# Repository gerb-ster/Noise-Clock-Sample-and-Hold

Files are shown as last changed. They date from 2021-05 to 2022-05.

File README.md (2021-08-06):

# Noise, Clock and S&H

This module is a sort of 3-in-1 module, containing 4 types of noise, a clock generator based on a 555 IC and a sample-and-hold section. It’s based on / inspired by the Noise & S&H module by Niklas Ronnberg. It has a slew function, which is really nice, use it quit a lot.

The noise colors are White, Blue, Pink & Red. They are created by filtering the white noise. There are 2 trimmer pots on the back, one to set the overal noise volume and one to set the pulse length of the clock output.

## Status: Finished

- done: first schematic & board design
- done: breadboard and test
- done: design frontpanel
- done: order PCB and build prototype

## Pot Values

Since the earlier schematic didn't include the pot values, here they are (schematics have also been updated)

Slew & Attn: 100k lin
Rate: 1M log

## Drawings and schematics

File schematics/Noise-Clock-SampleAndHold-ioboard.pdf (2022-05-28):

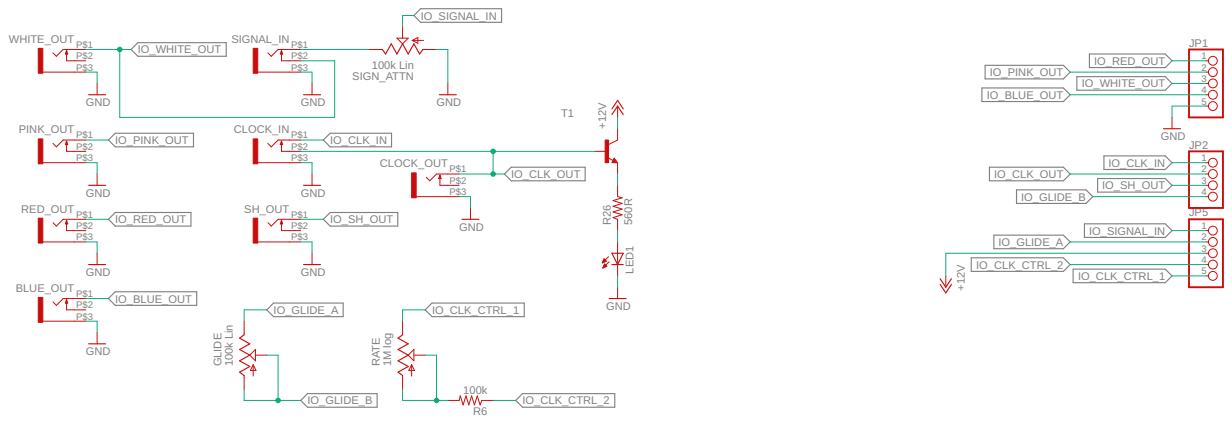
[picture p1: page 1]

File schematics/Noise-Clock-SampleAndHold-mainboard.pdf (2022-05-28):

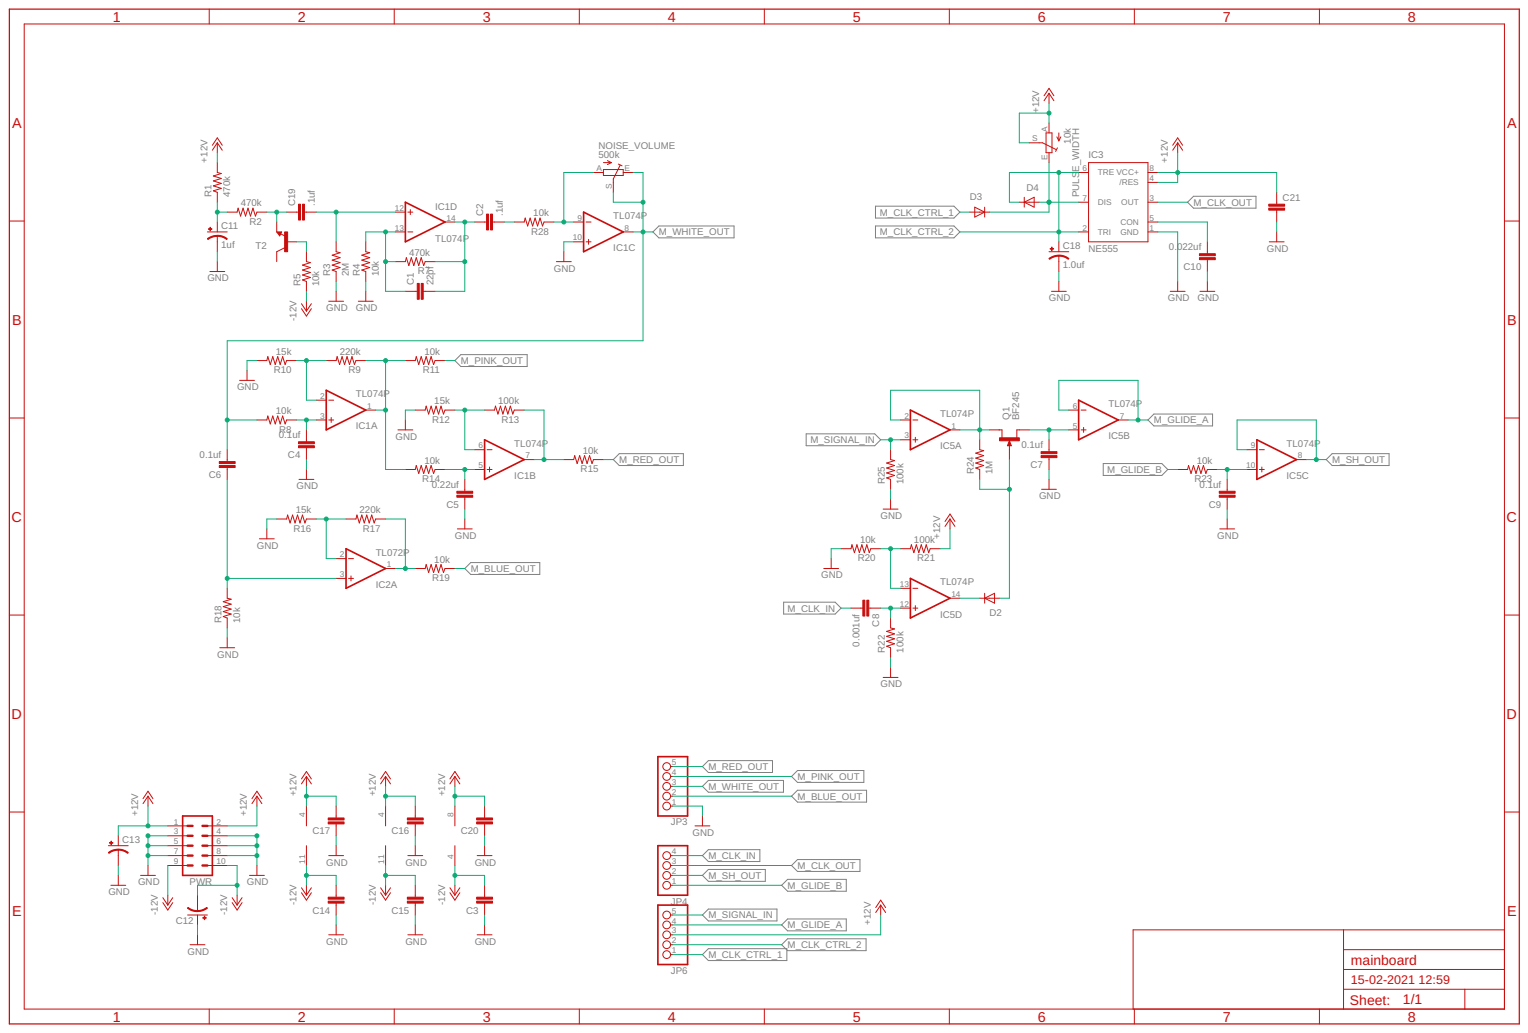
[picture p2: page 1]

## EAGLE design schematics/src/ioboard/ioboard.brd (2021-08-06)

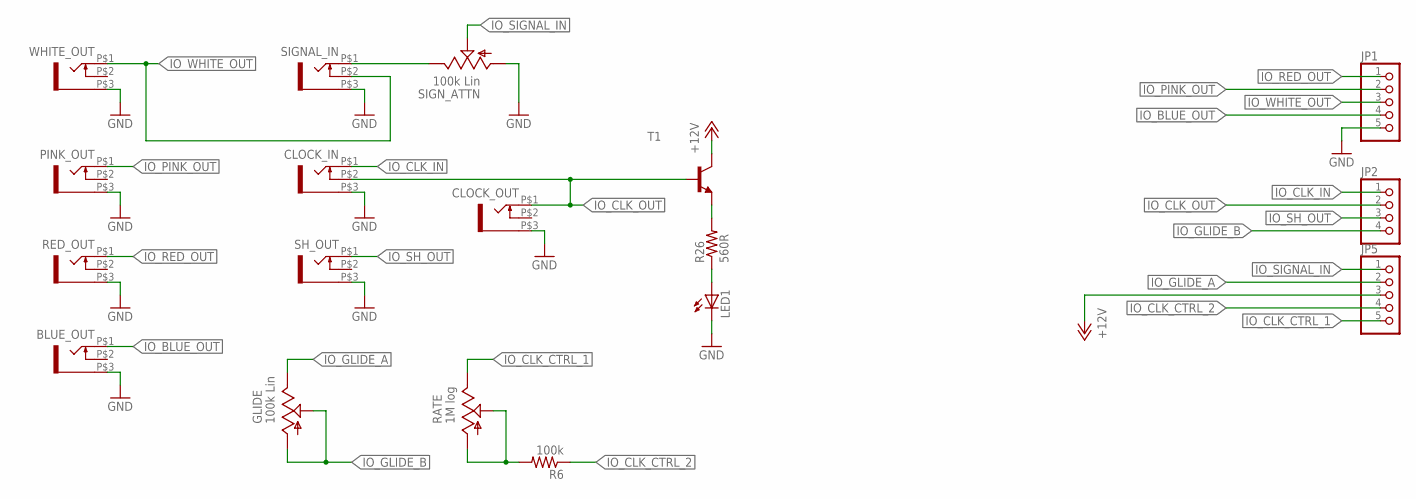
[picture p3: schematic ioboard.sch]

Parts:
BLUE_OUT: WQP-PJ301M-12_JACK
CLOCK_IN: WQP-PJ301M-12_JACK
CLOCK_OUT: WQP-PJ301M-12_JACK
GLIDE: 100k Lin; EVUF
JP1, JP5: PINHD-1X5; 1X05
JP2: PINHD-1X4; 1X04
LED1: LED3MM
PINK_OUT: WQP-PJ301M-12_JACK
R6: 100k; 0204/7
R26: 560R; 0204/7
RATE: 1M log; EVUF
RED_OUT: WQP-PJ301M-12_JACK
SH_OUT: WQP-PJ301M-12_JACK
SIGNAL_IN: WQP-PJ301M-12_JACK
SIGN_ATTN: 100k Lin; EVUF
T1: BC550-NPN-TO92-CBE; TO92-CBE
WHITE_OUT: WQP-PJ301M-12_JACK

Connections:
+12V: JP5.3, T1.C
GND: BLUE_OUT.P$3 (1), CLOCK_IN.P$3 (1), CLOCK_OUT.P$3 (1), JP1.5, LED1.K (C), PINK_OUT.P$3 (1), RED_OUT.P$3 (1), SH_OUT.P$3 (1), SIGNAL_IN.P$3 (1), SIGN_ATTN.1 (A), WHITE_OUT.P$3 (1)
IO_BLUE_OUT: BLUE_OUT.P$1 (2), JP1.4
IO_CLK_CTRL_1: JP5.5, RATE.3 (E)
IO_CLK_CTRL_2: JP5.4, R6.1
IO_CLK_IN: CLOCK_IN.P$1 (2), JP2.1
IO_CLK_OUT: CLOCK_IN.P$2 (3), CLOCK_OUT.P$1 (2), JP2.2, T1.B
IO_GLIDE_A: GLIDE.3 (E), JP5.2
IO_GLIDE_B: GLIDE.1 (A), GLIDE.2 (S), JP2.4
IO_PINK_OUT: JP1.2, PINK_OUT.P$1 (2)
IO_RED_OUT: JP1.1, RED_OUT.P$1 (2)
IO_SH_OUT: JP2.3, SH_OUT.P$1 (2)
IO_SIGNAL_IN: JP5.1, SIGN_ATTN.2 (S)
IO_WHITE_OUT: JP1.3, SIGNAL_IN.P$2 (3), WHITE_OUT.P$1 (2)
unnamed: SIGNAL_IN.P$1 (2), SIGN_ATTN.3 (E)
unnamed: LED1.A, R26.1
unnamed: R26.2, T1.E
unnamed: R6.2, RATE.1 (A), RATE.2 (S)

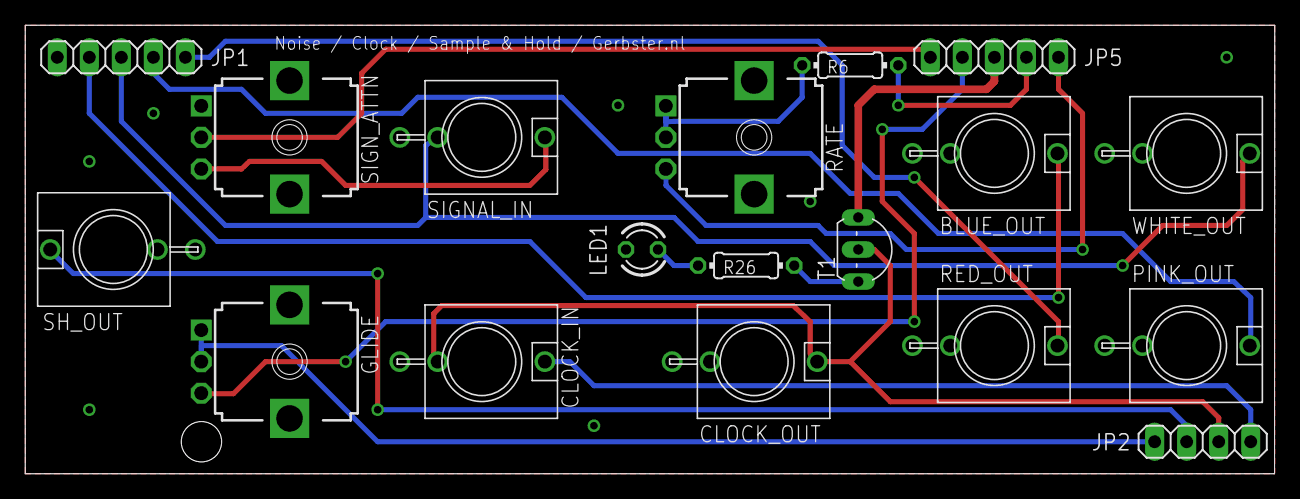
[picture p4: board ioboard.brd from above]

Board: 2 copper layers, 99.1 x 35.6 mm, 18 parts (0 on the bottom side), 18 nets.

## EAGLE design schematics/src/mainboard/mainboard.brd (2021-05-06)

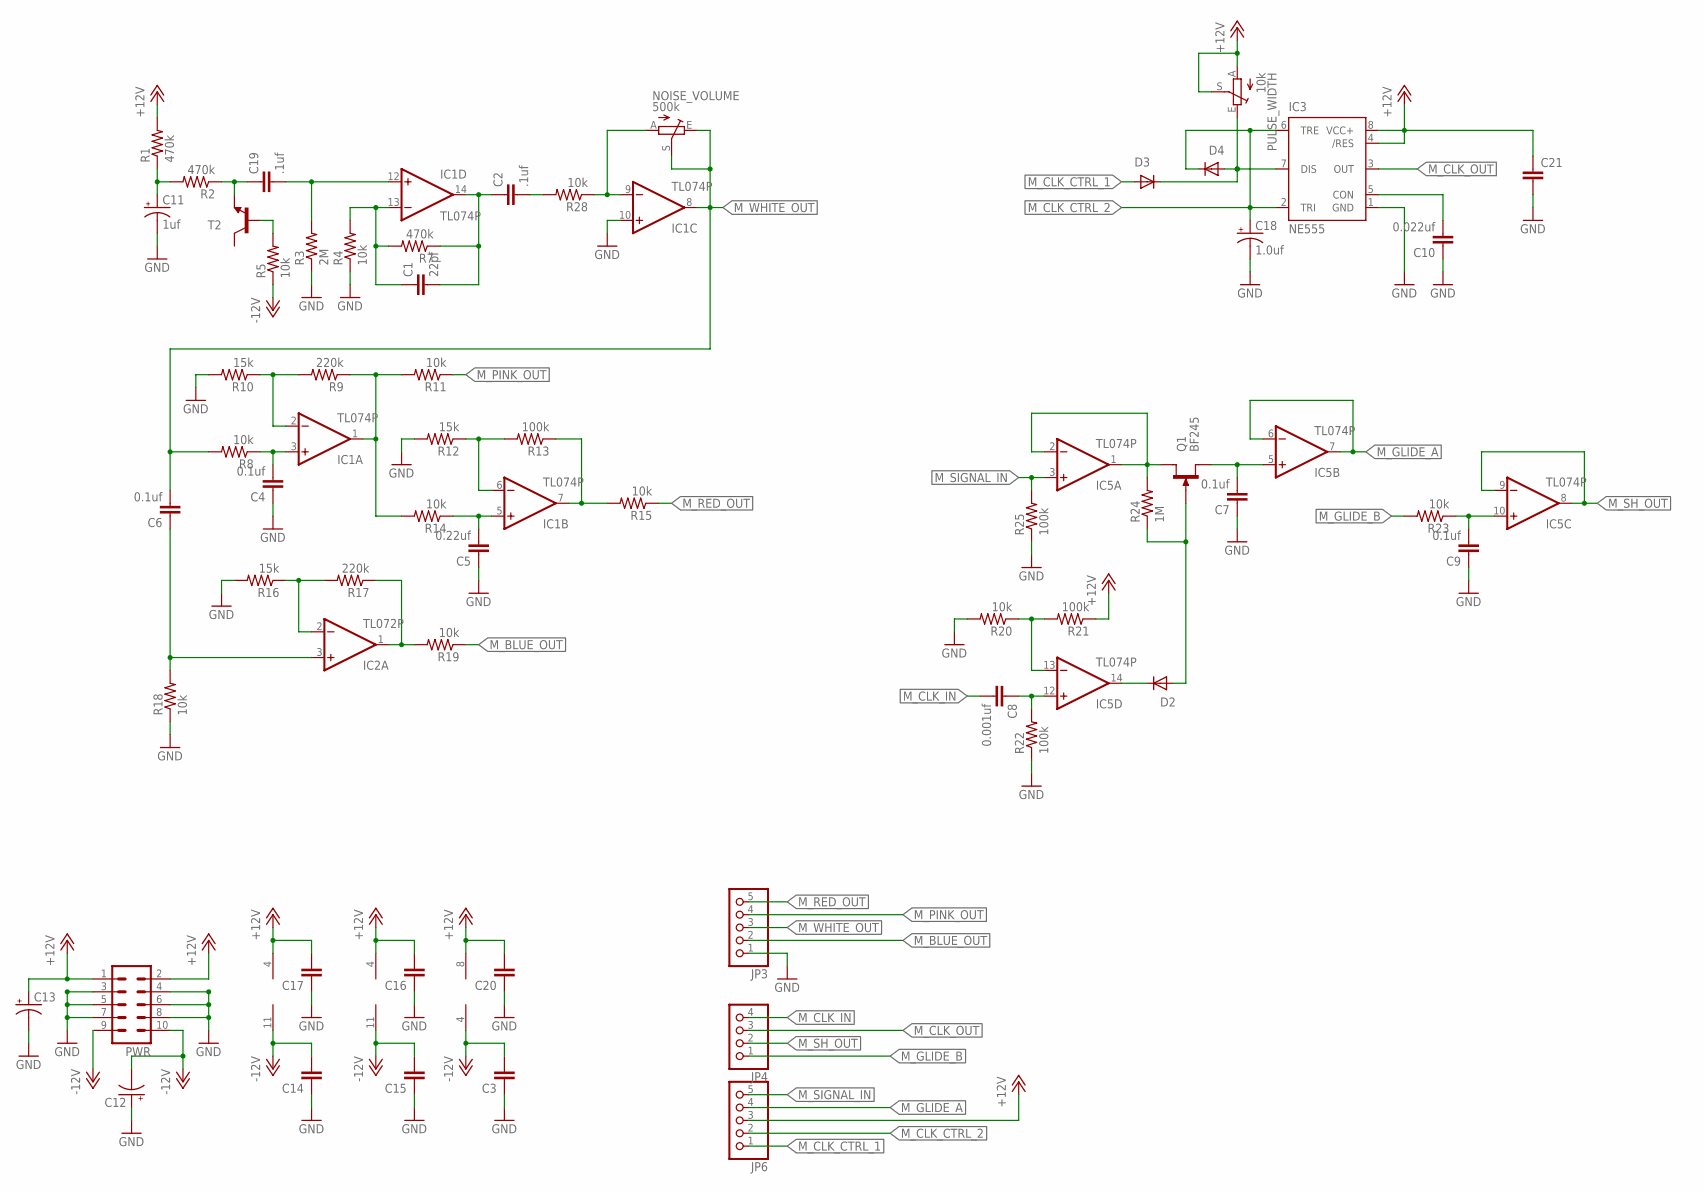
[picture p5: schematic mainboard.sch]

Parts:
C1: 22pf; C050-024X044
C2, C19: .1uf; C050-024X044
C3, C14, C15, C16, C17, C20, C21: C-EU050-024X044; C050-024X044
C4, C6, C7, C9: 0.1uf; C050-024X044
C5: 0.22uf; C050-024X044
C8: 0.001uf; C050-024X044
C10: 0.022uf; C050-024X044
C11: 1uf; E2,5-5
C12, C13: CPOL-USE2.5-5; E2,5-5
C18: 1.0uf; E2,5-5
D2, D3, D4: 1N4148DO35-7; DO35-7
IC1, IC5: TL074P; DIL14
IC2: TL072P; DIL08
IC3: NE555; DIL-08
JP3, JP6: PINHD-1X5; 1X05
JP4: PINHD-1X4; 1X04
NOISE_VOLUME: 500k; S64YW
PULSE_WIDTH: 10k; S64YW
PWR: ML10
Q1: BF245; SOT54C
R1, R2, R7: 470k; 0204/7
R3: 2M; 0204/7
R4, R5, R8, R11, R14, R15, R18, R19, R20, R23, R28: 10k; 0204/7
R9, R17: 220k; 0204/7
R10, R12, R16: 15k; 0204/7
R13, R21, R22, R25: 100k; 0204/7
R24: 1M; 0204/7
T2: 2N3904-NPN-TO92-EBC; TO92-EBC

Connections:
+12V: C13.+, C16.2, C17.2, C20.2, C21.1, IC1.4 (V+), IC2.8 (V+), IC3.4 (/RES), IC3.8 (VCC+), IC5.4 (V+), JP6.3, PULSE_WIDTH.A, PULSE_WIDTH.S, PWR.1, PWR.2, R1.2, R21.1
-12V: C3.2, C12.-, C14.2, C15.2, IC1.11 (V-), IC2.4 (V-), IC5.11 (V-), PWR.9, PWR.10, R5.1
GND: C3.1, C4.1, C5.1, C7.1, C9.1, C10.1, C11.-, C12.+, C13.-, C14.1, C15.1, C16.1, C17.1, C18.-, C20.1, C21.2, IC1.10 (+IN), IC3.1 (GND), JP3.1, PWR.3, PWR.4, PWR.5, PWR.6, PWR.7, PWR.8, R3.1, R4.1, R10.2, R12.2, R16.2, R18.1, R20.2, R22.1, R25.1
M_BLUE_OUT: JP3.2, R19.1
M_CLK_CTRL_1: D3.A, JP6.1
M_CLK_CTRL_2: C18.+, D4.C, IC3.2 (TRI), IC3.6 (TRE), JP6.2
M_CLK_IN: C8.2, JP4.4
M_CLK_OUT: IC3.3 (OUT), JP4.3
M_GLIDE_A: IC5.6 (-IN), IC5.7 (OUT), JP6.4
M_GLIDE_B: JP4.1, R23.2
M_PINK_OUT: JP3.4, R11.1
M_RED_OUT: JP3.5, R15.1
M_SH_OUT: IC5.8 (OUT), IC5.9 (-IN), JP4.2
M_SIGNAL_IN: IC5.3 (+IN), JP6.5, R25.2
M_WHITE_OUT: C6.2, IC1.8 (OUT), JP3.3, NOISE_VOLUME.E, NOISE_VOLUME.S, R8.2
unnamed: C19.1, R2.1, T2.E
unnamed: C11.+, R1.1, R2.2
unnamed: R5.2, T2.B
unnamed: C19.2, IC1.12 (+IN), R3.2
unnamed: C1.1, IC1.13 (-IN), R4.2, R7.2
unnamed: C1.2, C2.1, IC1.14 (OUT), R7.1
unnamed: C2.2, R28.2
unnamed: C4.2, IC1.3 (+IN), R8.1
unnamed: IC1.2 (-IN), R9.2, R10.1
unnamed: IC1.1 (OUT), R9.1, R11.2, R14.2
unnamed: IC5.1 (OUT), IC5.2 (-IN), Q1.D, R24.2
unnamed: IC1.6 (-IN), R12.1, R13.2
unnamed: IC1.7 (OUT), R13.1, R15.2
unnamed: C5.2, IC1.5 (+IN), R14.1
unnamed: D3.C, D4.A, IC3.7 (DIS), PULSE_WIDTH.E
unnamed: C6.1, IC2.3 (+IN), R18.2
unnamed: IC2.2 (-IN), R16.1, R17.2
unnamed: IC2.1 (OUT), R17.1, R19.2
unnamed: C10.2, IC3.5 (CON)
unnamed: IC5.13 (-IN), R20.1, R21.2
unnamed: C8.1, IC5.12 (+IN), R22.2
unnamed: IC1.9 (-IN), NOISE_VOLUME.A, R28.1
unnamed: D2.C, IC5.14 (OUT)
unnamed: D2.A, Q1.G, R24.1
unnamed: C7.2, IC5.5 (+IN), Q1.S
unnamed: C9.2, IC5.10 (+IN), R23.1

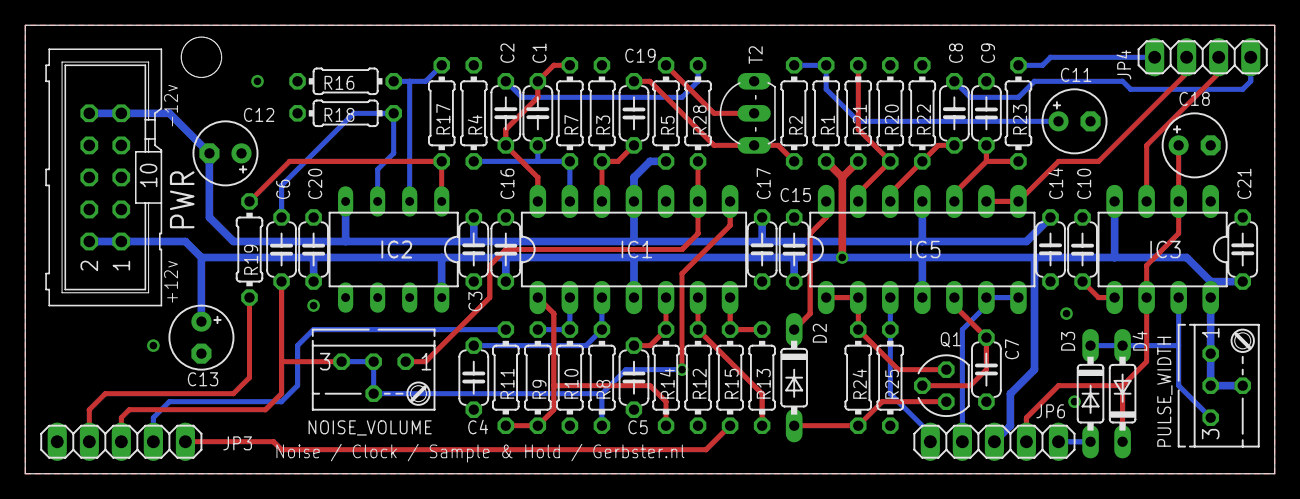
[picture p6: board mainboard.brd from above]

Board: 2 copper layers, 99.1 x 35.6 mm, 61 parts (0 on the bottom side), 41 nets.

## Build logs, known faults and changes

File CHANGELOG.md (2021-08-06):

# Changelog

All notable changes to this project will be documented in this file.

The format is based on [Keep a Changelog](https://keepachangelog.com/en/1.0.0/),
and this project adheres to [Semantic Versioning](https://semver.org/spec/v2.0.0.html).

## [1.0.0] - 2021-01-05

### Added

- Inintial repo setup

## [1.0.1] - 2021-08-06

### Changed

- Added valus of the pots to the schematic

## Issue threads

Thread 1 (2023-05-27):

BOM Missing Details

saddeus, 2023-05-27:
On the BOM for the mainboard, a number of capacitors do not have values listed.

gerb-ster, 2023-05-28:
Thank you for reporting this, I'll take a look at it.

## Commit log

2021-05-06 some files
    [NoiseSampleHold.brd, NoiseSampleHold.sch]
2021-05-07 Added files & structure
    [Noise-Clock-SampleAndHold-ioboard.GBL, Noise-Clock-SampleAndHold-ioboard.GBO, Noise-Clock-SampleAndHold-ioboard.GBP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]
2021-08-06 Updated some schematics and docs
    [Noise-Clock-SampleAndHold-ioboard.GBL, Noise-Clock-SampleAndHold-ioboard.GBO, Noise-Clock-SampleAndHold-ioboard.GBP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]
2021-08-10 Fixed some bugs and updated documentation
    [Noise-Clock-SampleAndHold-ioboard.XLN, Noise-Clock-SampleAndHold-mainboard.XLN, gerber_job.gbrjob]
2022-04-20 Some updates & bugfixes
    [Noise-Clock-SampleAndHold-ioboard.XLN, Noise-Clock-SampleAndHold-mainboard.XLN, gerber_job.gbrjob]
2022-04-22 Fixed schematics & descriptions
    [Noise-Clock-SampleAndHold-ioboard.XLN, Noise-Clock-SampleAndHold-mainboard.XLN, gerber_job.gbrjob]
2022-05-17 Updated Firmware
    [Noise-Clock-SampleAndHold-ioboard.XLN, Noise-Clock-SampleAndHold-mainboard.XLN, gerber_job.gbrjob]
2022-05-18 Updated Faceplates
    [Noise-Clock-SampleAndHold-ioboard.XLN, Noise-Clock-SampleAndHold-mainboard.XLN, gerber_job.gbrjob]
2022-05-18 Fixed issues
    [Noise-Clock-SampleAndHold-ioboard.XLN, Noise-Clock-SampleAndHold-mainboard.XLN, gerber_job.gbrjob]
2022-05-21 Fixed schematics
    [Noise-Clock-SampleAndHold-ioboard.XLN, Noise-Clock-SampleAndHold-mainboard.XLN, gerber_job.gbrjob]
2022-05-28 General updates
    [Noise-Clock-SampleAndHold-ioboard.GKO, Noise-Clock-SampleAndHold-mainboard.GKO, copper_bottom.gbr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]
